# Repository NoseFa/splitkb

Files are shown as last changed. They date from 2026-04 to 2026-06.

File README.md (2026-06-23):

# Nordic split

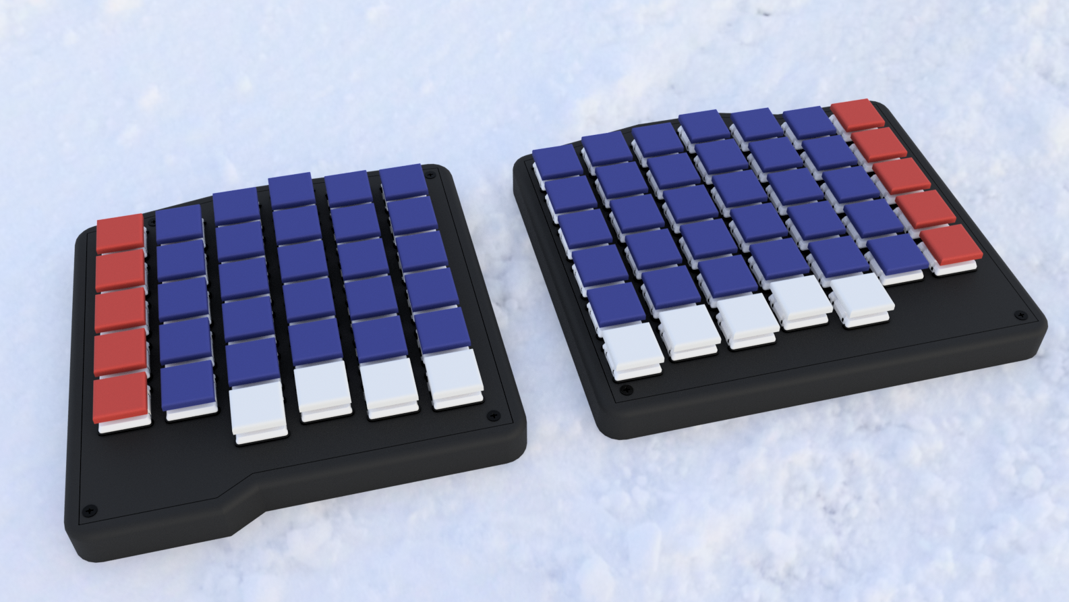
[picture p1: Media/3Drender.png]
3D render


A split low-profile wireless keyboard with a nordic ISO layout. I used the [Caldera Keyboard by Christian Selig](https://github.com/christianselig/caldera-keyboard) as inspiration and it clearly shows in the design. Still the keyboard uses a nice!nano like microcontroller based on the same NRF52840, ZMK as the firmware and a custom pcb with Choc V1 hotswap sockets. The keyboard also has an ortholinear layout which can be more ergonomic for some users.

The project was made and designed as a part of Hack Club's [Fallout](https://fallout.hackclub.com/) event where people make hardware projects and get a chance to go to Shenzhen, China. This was also one of my first electronics projects.

## Highlights

* Hotswapping
* Open-source
* ZMK firmware (ZMK studio support)
* Wireless
* Nordic layout
* total of 74 keys

## Why it exists?

The project was made because I wanted a split keyboard but needed a nordic layout for my day to day stuff (I need the letters Ä, Ö, Å). So the nordic split was born. I took inspiration from the Caldera keyboard by Christian Selig. It's low profile so it can be transported easily around and it's also wireless so no need for annoying dual or split cables for connecting to a computer or laptop.

This is the first keyboard I have designed so the keymap and layout were made with some educated guess work. They might be updated later down the line. I will update this repo with the most recent keymap I use. Even though it was designed as nordic layout first. The keyboard could also be used by people with non-nordic layouts and you could use the extra row of keys on the right side as shortcut or macro keys. Of course also the pcb could be edited and these keys removed if you don't want them. This keyboard has ZMK studio support so you can change the keymap in the [ZMK.studio](https://zmk.studio) web app.

## BOM summary

* Pro Micro NRF52840 [Aliexpress](https://www.aliexpress.com/item/1005007205026373.html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)
* Kailh choc v1 low-profile switches [Aliexpress](https://www.aliexpress.com/item/1005008644185126.html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)
* 304050 Lithium-Polymer battery [42Keebs.eu](https://42keebs.eu/shop/parts/lithium-polymer-battery/?attribute_size=304050%20(600%20mAh))
* Kailh Low Profile Choc hotswap sockets [Aliexpress](https://www.aliexpress.com/item/1005011893351142.html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)
* PCB [JLCPCB](https://cart.jlcpcb.com/quote?spm=jlcpcb.Public.2006)
* M2x8mm screws [Aliexpress](https://www.aliexpress.com/item/1005006995421098.html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)
* M2 3mm OD heated inserts [Aliexpress](https://www.aliexpress.com/item/1005006071488810.html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)
* SOD-123 Diodes [Aliexpress](https://www.aliexpress.com/item/1005007536719404.html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)
* Kailh choc V1 A keycaps [Aliexpress](https://www.aliexpress.com/item/1005009262759706.html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)
* Anti-slip pads [Aliexpress](https://www.aliexpress.com/item/1005007438396940.html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)

Total price for the whole build excluding 3d prints is 159.26€.

You can find the full [BOM here](BOM.csv). It includes pricing, amount of parts, extra info etc.

## Build Guide Summary

1. Order PCB and other parts.
2. Order or print the case.
3. Solder parts to the PCBs (Diodes, hotswap-sockets, microcontroller)
4. Install the heated threaded inserts to the spots in the case (4 per side)
5. Install the PCB to the case.
6. Install top plate.
7. Install the choc switches to the sockets and keycaps.
8. Flash software (Check software section)
9. Enjoy!

More detailed build guide is available in the [build guide.md file](buildGuide.md).

## Software

See [Software.md](./Software/software.md) for more info about software and software installation instructions. The software source code files are in a different repo ([NoseFa/nordic-split-zmk](https://github.com/NoseFa/nordic-split-zmk))

## PCB

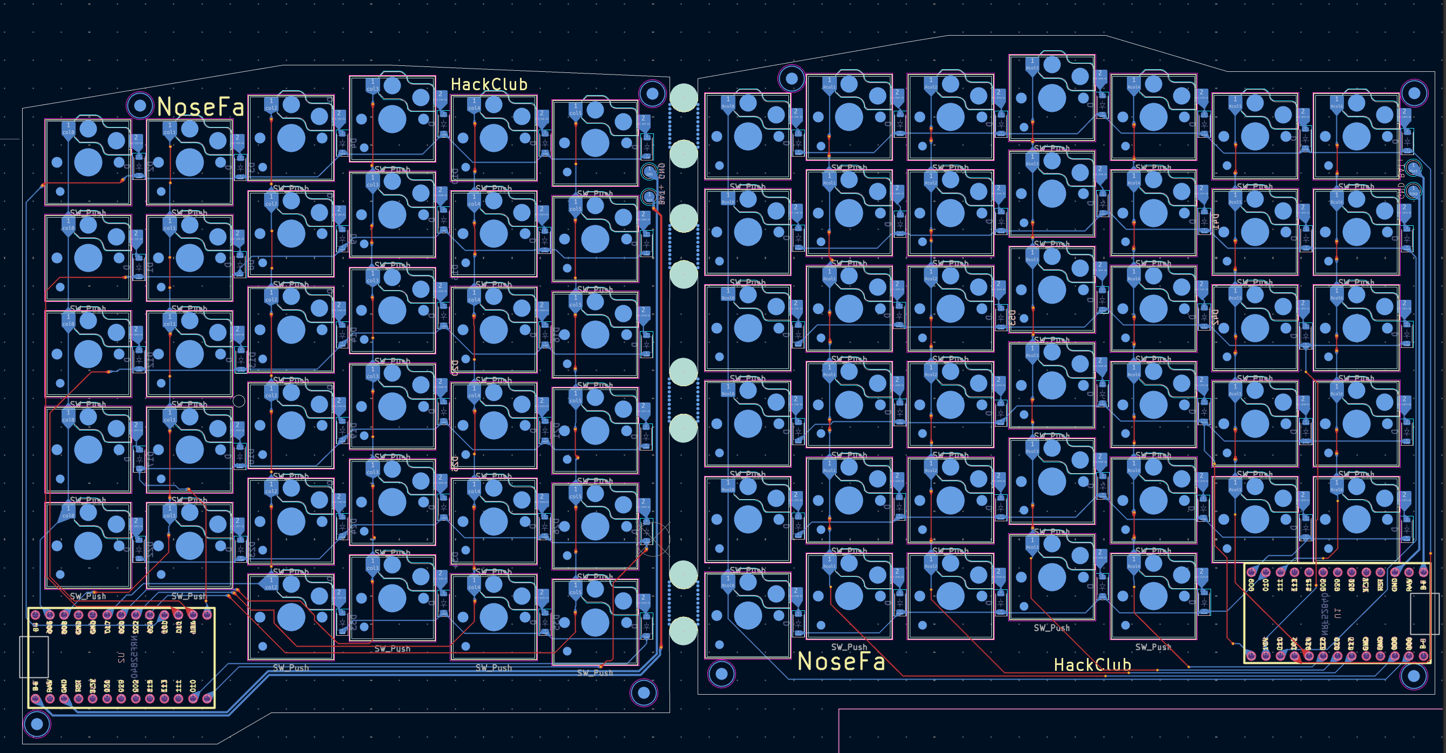
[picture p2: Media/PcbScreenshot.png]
PCB


Here is a picture of the left side PCB. You can see the switches, traces and a spot for the microcontrollers. The PCBs are seperated by mouse bites in the middle. Unlike some other split keyboards the Nordic Splits halves aren't mirrored but instead the right side has an extra row of keys primarly needed to support the Nordic layout.

The pcb was designed in KiCad by me. You can view the files in the [Kicad folder](./KICAD/splitkb).

Here is also the schematic which is split into three different pages. One for each side and one main page that has the mousebites and links the pages together.

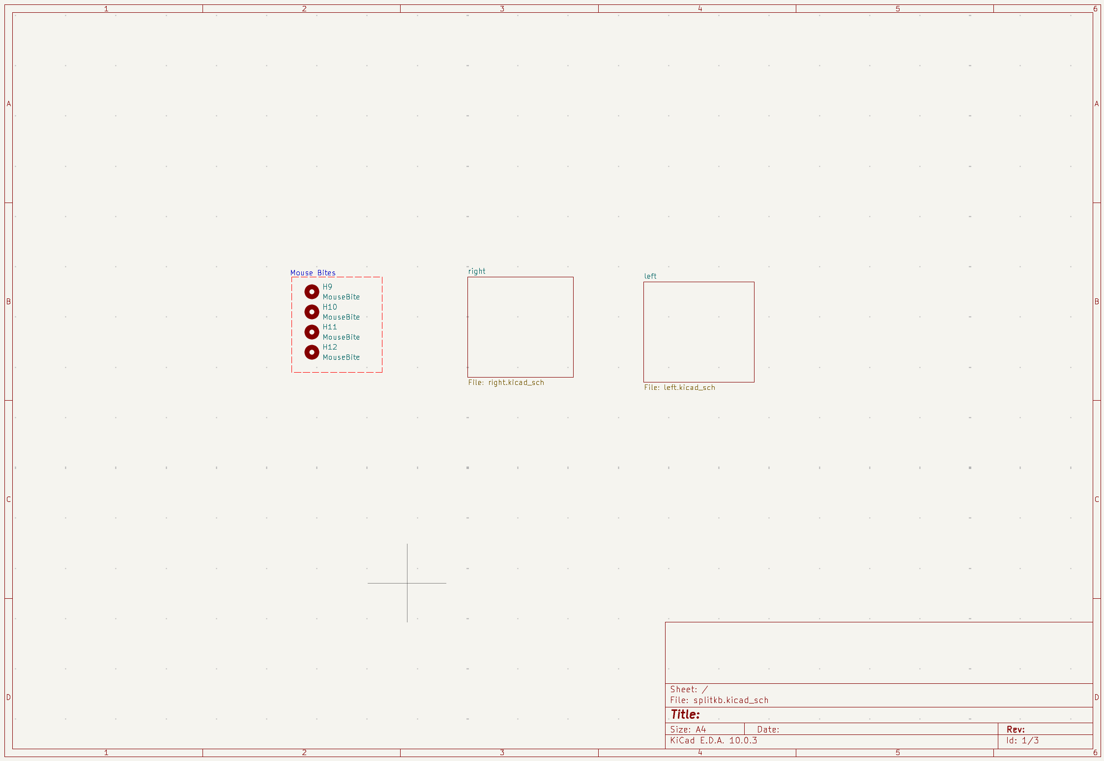
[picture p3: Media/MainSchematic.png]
Main Schematic


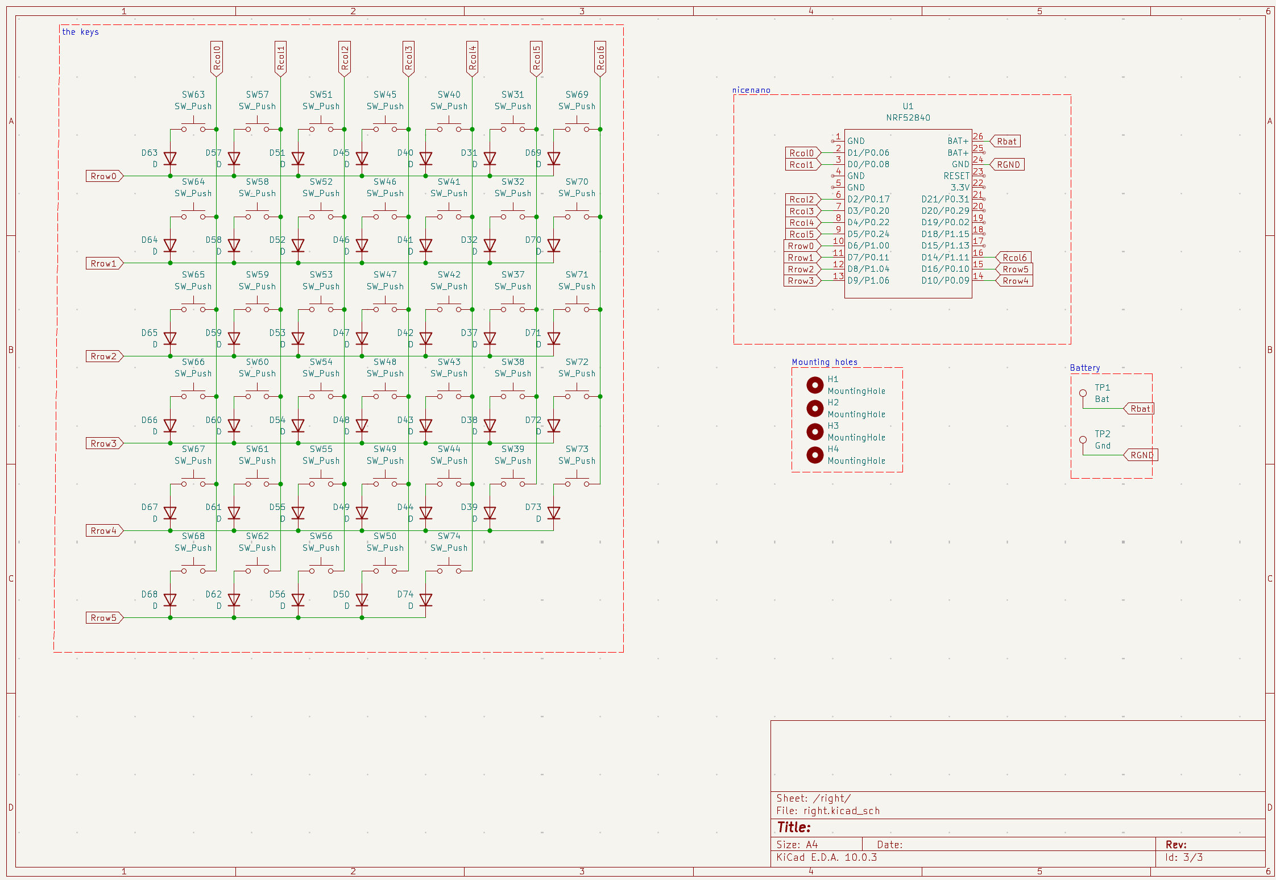
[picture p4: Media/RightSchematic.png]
Right side Schematic


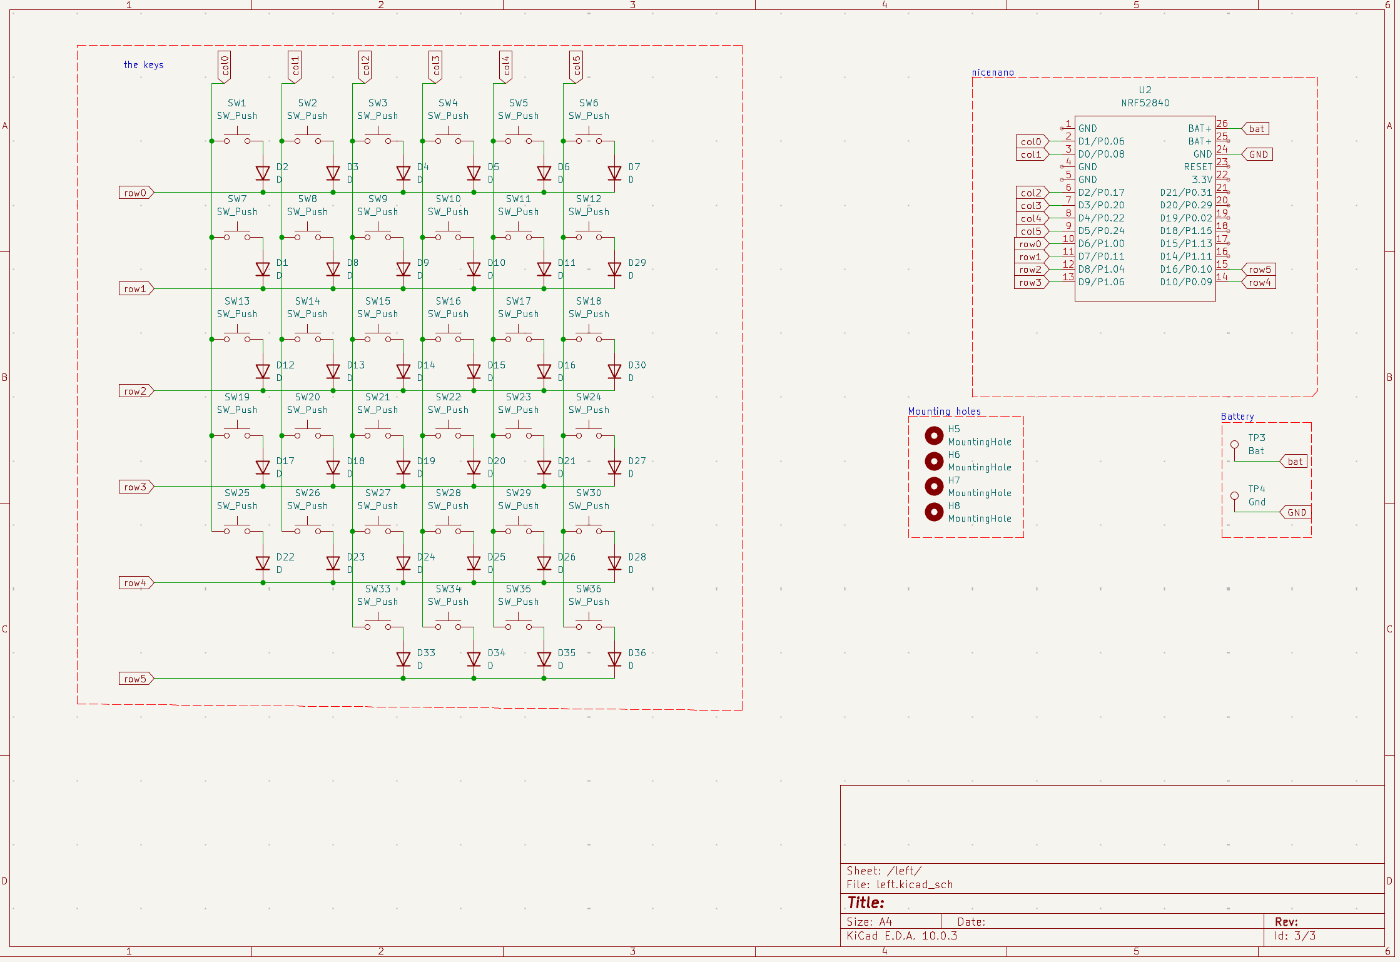
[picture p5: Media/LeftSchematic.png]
Left side Schematic


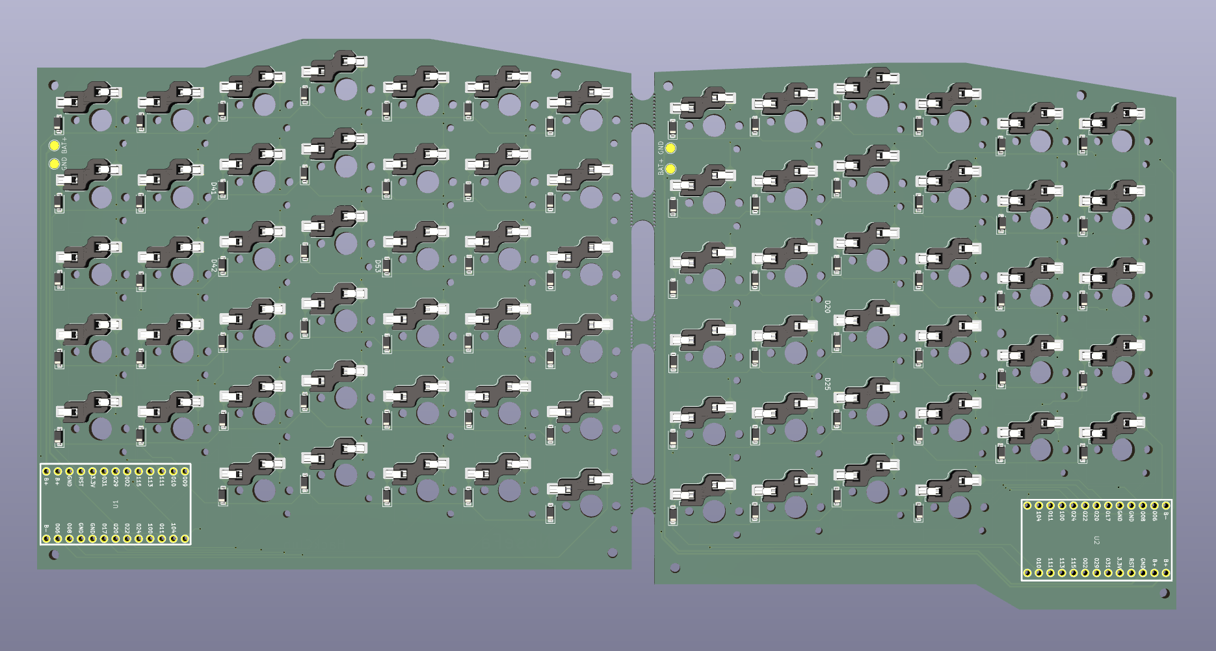
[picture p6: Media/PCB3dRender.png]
3D render of the pcb


For ordering the PCB I used JLCPCB. You can find the gerber files as a zip in the [Production files folder](./KICAD/ProductionFiles/NordicSplitGerber.zip)

## 3D files

3d Files are seperated into 2 folders. Full project which has the .fz3 and .step versions of the whole 3D project. The PCB was exported when I finished the the edge cuts so some holes next to the micro controller might be different. I didn't include the microcontroller or the SMD diodes in the 3d project but I did check that they fit.

The 3d files for the switches in the Fusion project are from [printables](https://www.printables.com/model/716753-kaliah-choc-v1-v2-dummy/files). They are made by [cobypear](https://www.printables.com/@cobypear_1543945). They are originally from the same library as I used in kicad which is the [kiswitch library](https://github.com/kiswitch/kiswitch/tree/main/library/3dmodels/3d-library.3dshapes). You can find the original files from the link.

## Zine Page

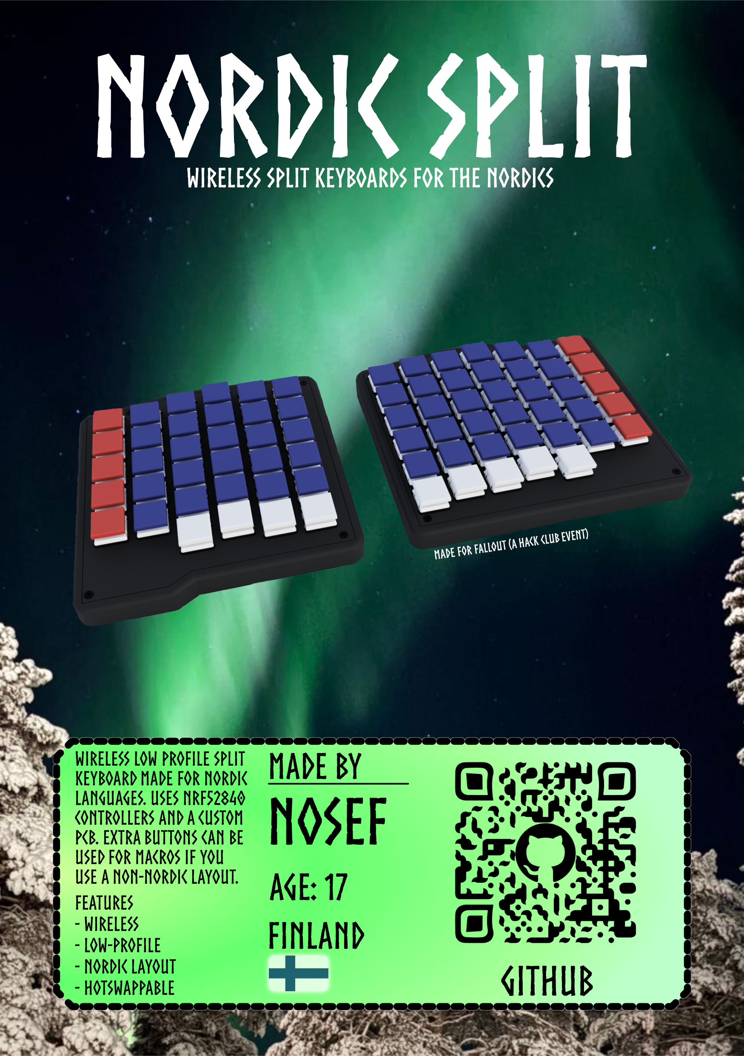
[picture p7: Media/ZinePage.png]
Zine Page


Zine page is also available as a [PDF](./ZinePage/ZinePage.pdf).
Background picture was taken by my dad when we went up north.

## Demo

A video of the keyboard in use.

SOON (When I get the parts).

## Acknowledgements

* Thanks to [Hack Club](https://hackclub.com/) [Fallout](https://fallout.hackclub.com/). If you want to view the project I made for Fallout including journals you can view it on [the event page](https://fallout.hackclub.com/projects/156).

* [Caldera Keyboard by Christian Selig](https://github.com/christianselig/caldera-keyboard) was used as inspiration and [his video](https://www.youtube.com/watch?v=7UXsD7nSfDY) was a great watch. My design is clearly inspired by him.

## Tools used

### Design

* [KiCad](https://www.kicad.org/) (PCB design)
* [Fusion](https://www.autodesk.com/products/fusion-360/personal) (Case design)
* [Excalidraw](https://app.excalidraw.com/) (Notetaking)
* [ZMK CLI](https://zmk.dev/docs/zmk-cli) (Firmware creation)

### Assembly

* Soldering iron
* Screwdriver for the M2 screws
* Computer to flash the software.
* USB-C cable

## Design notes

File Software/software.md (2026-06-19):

# Software

> [!WARNING]
> The software source code files are in a different repo ([NoseFa/nordic-split-zmk](https://github.com/NoseFa/nordic-split-zmk))

The keyboard is running ZMK which is the standard software used for wireless diy custom keyboards. Here is the [official docs for ZMK](https://zmk.dev/docs/features/split-keyboards). You might want to read this if you want to know more. I will still provide some instructions and info here as well as my own config files in the [the software repo](https://github.com/NoseFa/nordic-split-zmk) but if you need something else you should check the ZMK page.

The main points you might want to know are that one of the sides will be the host and it will drain more battery then the other side. This is because the "host" side will be communicating between the computer and the other side and the non host side will be just communicating with the host side. With the size of the batteries I used this wont be an issue but this technically means that you could use a bit of a smaller battery on one side and have the same battery life as the host side. The software is configured using a different config files that have the keymap and gpio layout etc. Then ZMK has a github action that can create the .uf2 file. The ready to install firmware is available in [the firmware folder](./firmware/). I have added ZMK studio support so some configuration of the keymap can be done through [the ZMK studio web tool](https://zmk.studio/). There is also a [native app](https://zmk.studio/download). This can be useful if you want to change the keymap but don't want to make a whole new .uf2 software file.

If you want to view to more specific config files and builds you can view [the software repo](https://github.com/NoseFa/nordic-split-zmk). If you're just looking to install the firmware you can use the files in the [firmware folder](./firmware). Remember that there are different files for each side.

## Installation

For installing you can grab the .uf2 files from the software folder. You can also edit the config files if you want to modify them and make your own .uf2 files. You can enter the flashing mode of the ProMicro by shorting the Rst(Reset) and GND(Ground) pins for 0,5swhile connecting to your computer and the controller should show up as a Nice!Nano storgae media device. You can drop in the .uf2 file on it and it should install it. You have seperate firmware files for each side ([`nordic1_left-nice_nano_v2-zmk.uf2`](./firmware/nordic1_left-nice_nano_v2-zmk.uf2) and [`nordic1_right-nice_nano_v2-zmk.uf2`](./firmware/nordic1_right-nice_nano_v2-zmk.uf2)) check that you have the right one before you flash it. There are different layouts so this is important. After flashing them they should boot into the ZMK firmware and they should link together automatically through their paring process. See [the ZMK troubleshooting guide](https://zmk.dev/docs/troubleshooting/connection-issues). The keyboard should also become visible as a bluetooth device you can connect to. Keep in mind that only one device will show up and not both halves seperately.

## Keymaps

Here are the two layers included in the firmware files. There are also two empty layers that you can use using ZMK studio to configure anything you want without having to run the build action again. The icons in the previews are from Iconify. These keymaps are made with the nordic layout in mind and they are the first keymap I have created so they can be a little bit weird.

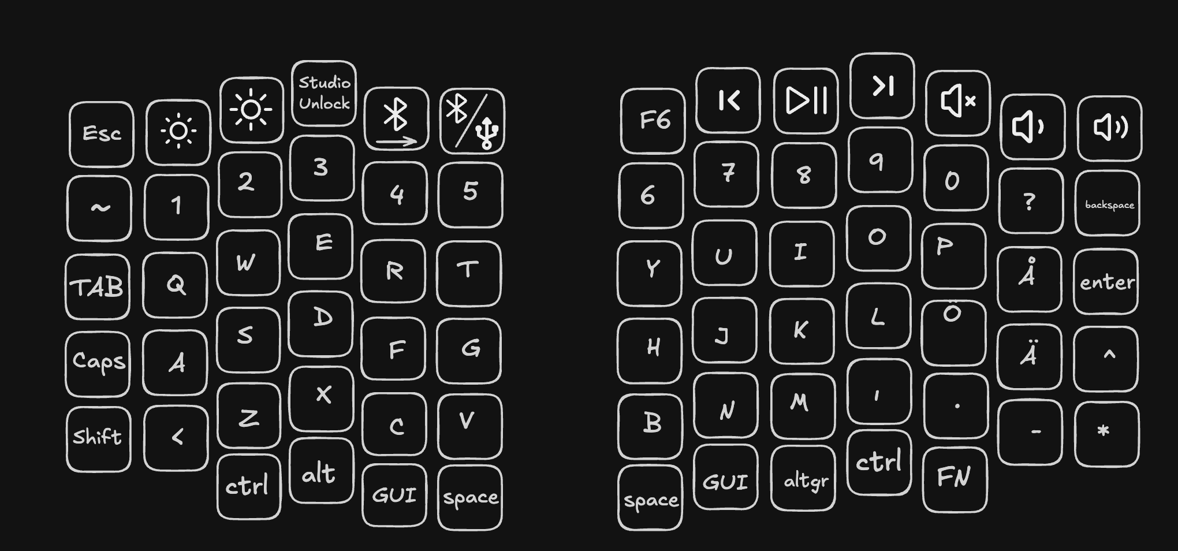
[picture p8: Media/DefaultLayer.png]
Default QWERTY layer


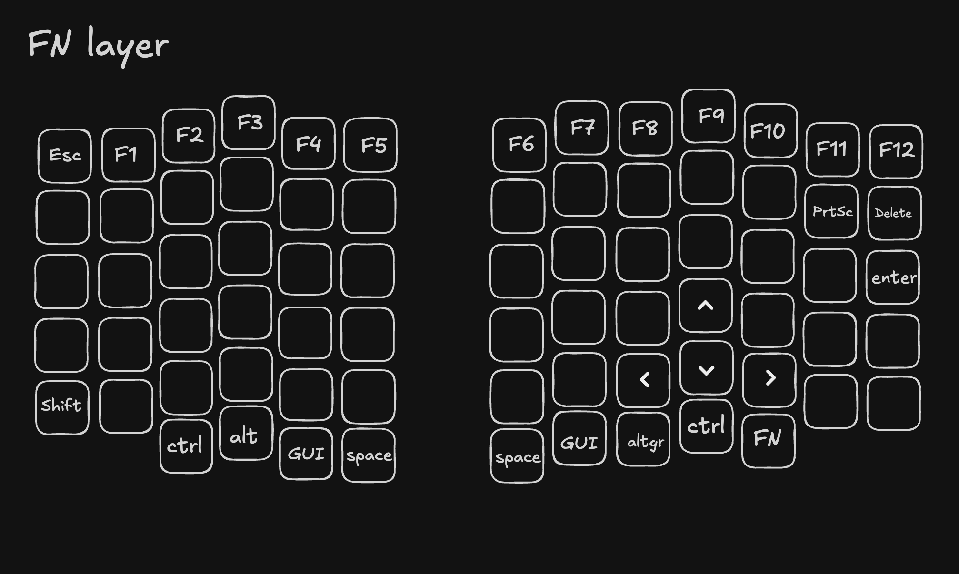
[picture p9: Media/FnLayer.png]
Function layer


## ZMK studio

ZMK studio is a tool provided by ZMK and for which I have added support in the firmware provided. You can use the easy to use GUI to change the keymap. The changes can be made even while the board is still connected to your computer and doesn't require reflashing. I have added 2 extra layers for which you can use for what ever you like. These have been left empty for now and should be configured by what you want. If you want to switch from the nordic keymap thats also made easier by ZMK studio and not having to flash the firmware again.

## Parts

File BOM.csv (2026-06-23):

Component | Price per order amount | parts needed | Shipping | Total price (For specific components) | Links | Extra info
Pro Micro NRF52840 | 4.13€ | 2 | Free | 8.23€ | https://www.aliexpress.com/item/1005007205026373.html?curPageLogUid=OxA2oroU7gov
Kailh Low Profile Choc Switches (brown) | 40.02€ for 80 switches | 74 | Free | 40.02€ | https://www.aliexpress.com/item/1005008644185126.html?curPageLogUid=ON5BcLwWvUu1
304050 Lithium-Polymer battery | 8.79€ for 1 pcs | 2 | 11.92€ | 29.50€ | https://42keebs.eu/shop/parts/lithium-polymer-battery/?attribute_size=304050%20(600%20mAh) | Needs to be ordered from within the EU to pass customs. If you live outside the EU you should look at local providers or on aliexpress
Kailh Low Profile Choc hotswap sockets | 8.58€ for 90 pieces | 74 | Free | 8.58€ | https://www.aliexpress.com/item/1005011893351142.html?curPageLogUid=nRsxJkAXhesI
PCB | 16.36€ for 5 pcs | 1 needed but is 5 minimum order amount. | 22.51€ + 9.92€ (Customs and taxes) | 48.79€ | https://cart.jlcpcb.com/quote?spm=jlcpcb.Public.2006 | Used europacket as the shipping option because they handle the taxes and it was the cheapest option.
M2x8mm screws | 0.86€ for 100 pcs | 4 | Free | 0.86€ | https://www.aliexpress.com/item/1005006995421098.html?curPageLogUid=HEtOGF0Rf2DI
M2 3mm OD L 3mm heated inserts | 1.23€ for 30 pcs | 4 | Free | 1.23€ | https://www.aliexpress.com/item/1005006071488810.html?curPageLogUid=m7Avo8Kp89dD
SOD-123 diodes | 1.43€ for 100pcs | 74 | Free | 1.43€ | https://www.aliexpress.com/item/1005007536719404.html?curPageLogUid=43hY8FWrAoHt
Kailh choc 1350 V1 A keycaps | 22.99€ for 90 pcs | 74 | Free | 25.73€ | https://www.aliexpress.com/item/1005009262759706.html?curPageLogUid=vcYL3e40gH5n
4pcs anti-slip black rubber feet | 0.87€ for 4pcs | 8 | Free | 1.74€ | https://www.aliexpress.com/item/1005007438396940.html?scm_id=1007.40050.354490.0&scm-url=1007.40050.354490.0 | The purchase limit is 4 per person but you can order them from here as well. https://www.aliexpress.com/item/1005012156552297.html?scm_id=1007.40050.354490.0&scm-url=1007.40050.354490.0 . They are the same.
Total price of all components: |  |  |  | 166.11€
NOTE!
Prices include VAT unless specified otherwise. (Everything except the JLCPCB order)
Some aliexpress pricing includes deals and first time buyer benefits etc. You might want to look for parts that have better deals at the time you are buying.
3D print pricing not included since I'm self printing. JLC3DP can print the parts for around 32€ depending on the material etc

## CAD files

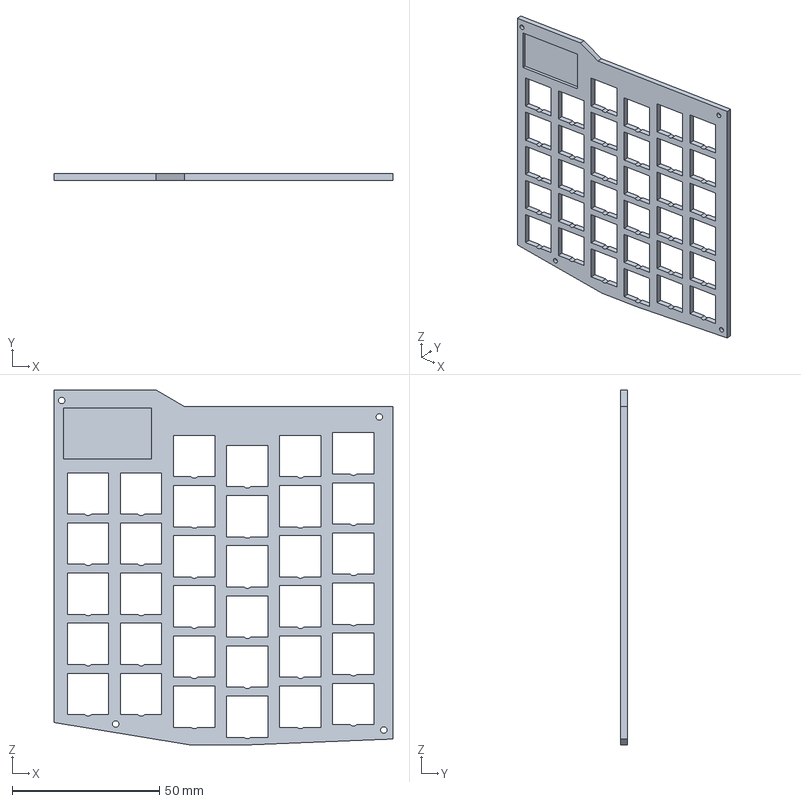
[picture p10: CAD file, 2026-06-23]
3dFiles/3dPrint/LeftSide/LeftSideTopPlate.step
114.8 x 2.50 x 120.4 mm

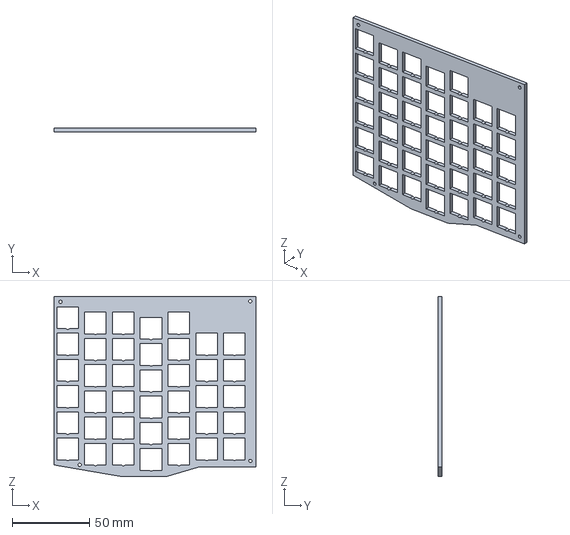
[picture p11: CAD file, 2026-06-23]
3dFiles/3dPrint/RightSide/RightSideTopPlate.step
130.8 x 2.50 x 116.8 mm

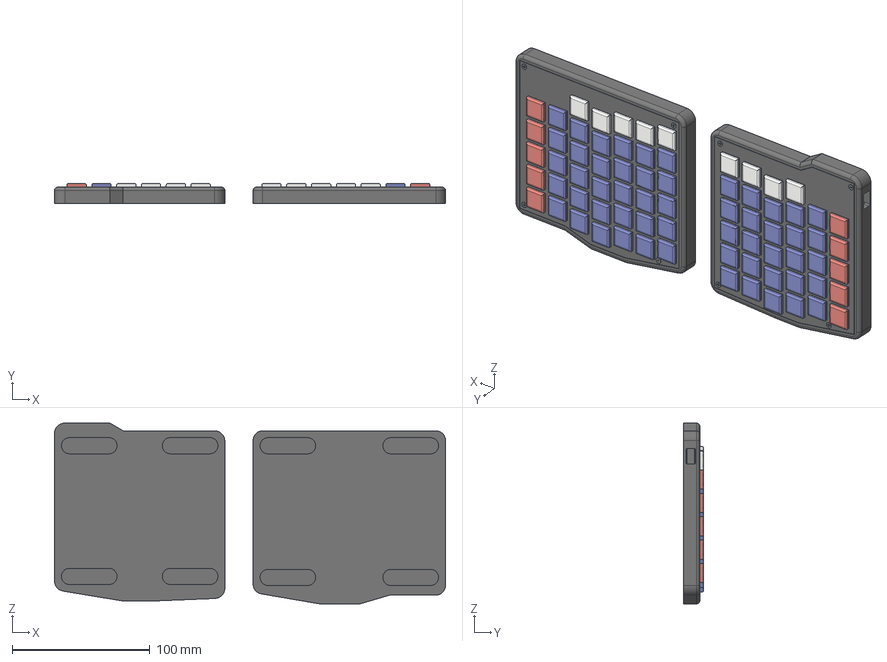
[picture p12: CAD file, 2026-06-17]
3dFiles/FullProject/SplitKbBothSides.step
284.1 x 14.4 x 131.4 mm
RightSideSplitKb
LeftSideSplitKb
PN-EN ISO 7046-1 - M2 x 8 - H Steel 4.6 Black x 8

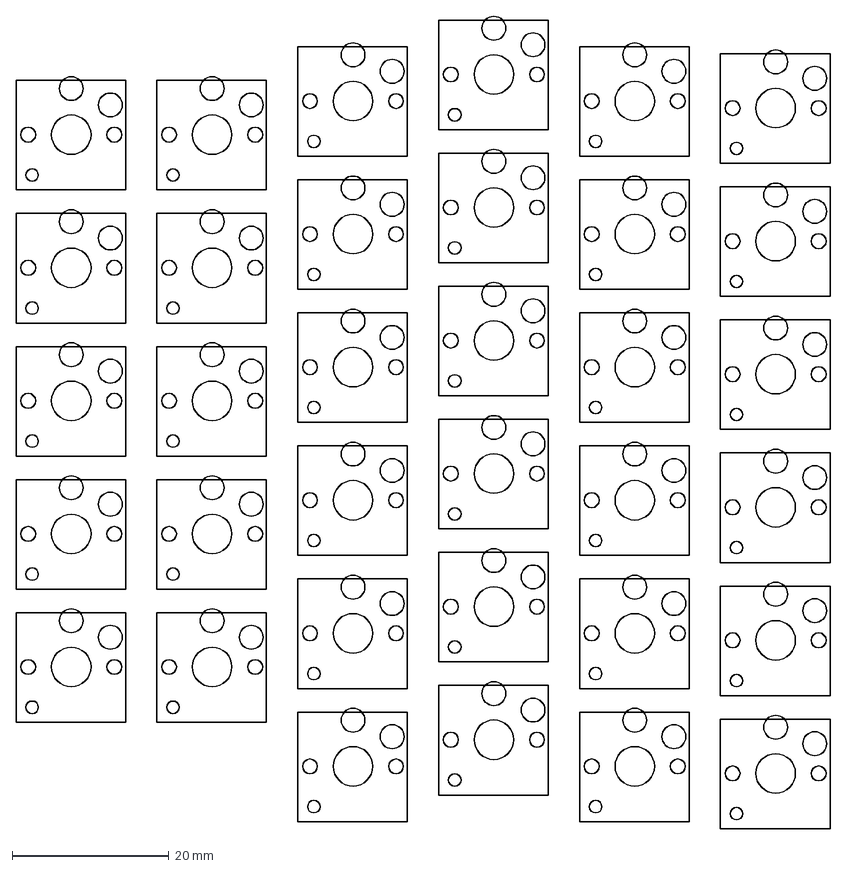
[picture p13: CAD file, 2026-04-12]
KICAD/splitkb/SketchLeft.dxf
104.0 x 103.8 mm

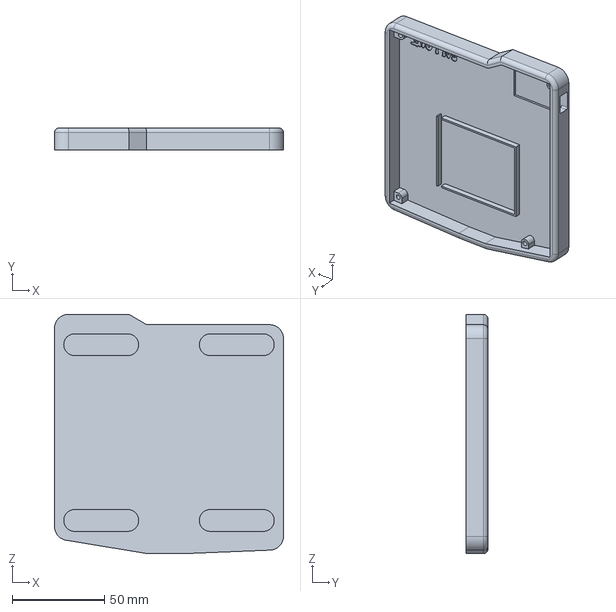
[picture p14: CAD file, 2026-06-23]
3dFiles/3dPrint/LeftSide/LeftSideOuterShell.step
123.8 x 11.9 x 129.4 mm

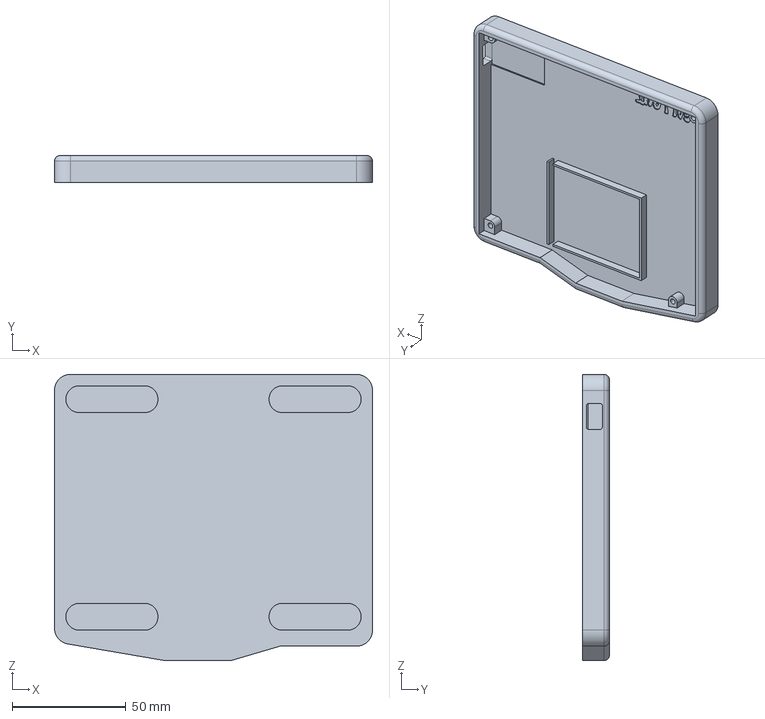
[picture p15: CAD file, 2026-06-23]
3dFiles/3dPrint/RightSide/RightSideOuterShell.step
139.8 x 11.9 x 125.8 mm

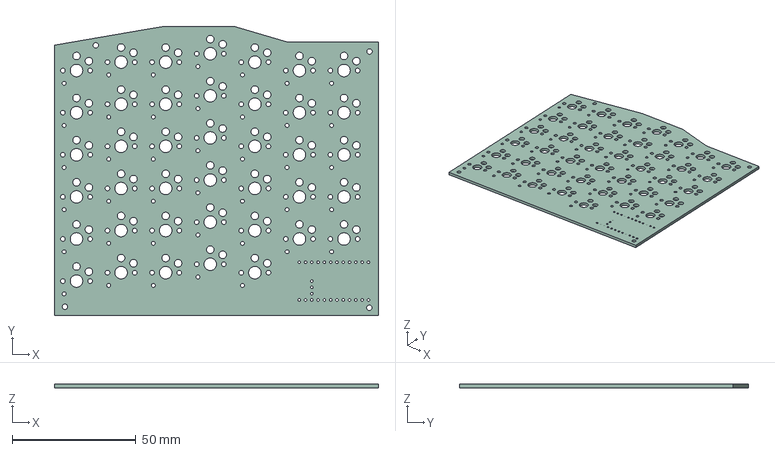
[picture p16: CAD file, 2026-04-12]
KICAD/splitkb/splitkb.step
130.8 x 116.8 x 1.51 mm

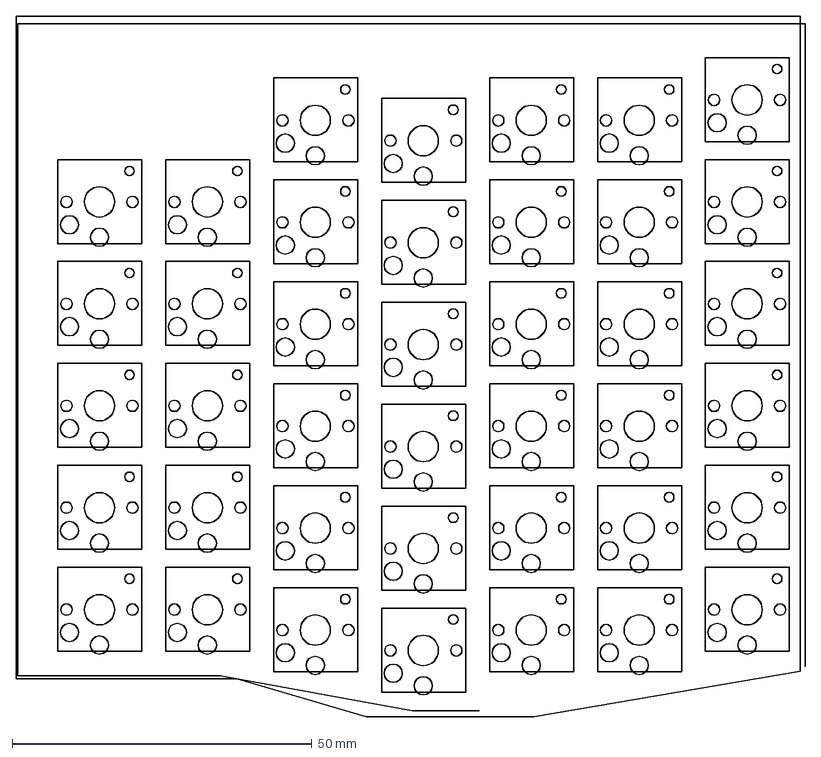
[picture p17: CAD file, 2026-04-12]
KICAD/splitkb/SketchRight.dxf
131.6 x 116.8 mm

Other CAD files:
3dFiles/3dPrint/LeftSide/LeftSideOuterShell.3mf
3dFiles/3dPrint/LeftSide/LeftSideTopPlate.3mf
3dFiles/3dPrint/RightSide/RightSideOuterShell.3mf
3dFiles/3dPrint/RightSide/RightSideTopPlate.3mf
3dFiles/FullProject/SplitKbBothSides.f3z

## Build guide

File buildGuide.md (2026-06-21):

# Build guide

This will cover building the physical keyboard. Part choices and ordering will be covered first.

## Ordering parts

First you need to order the PCBs from a PCB manufacturer. (Technically nothing prevents you from hand wiring this keyboard but it would require some redesigning of the case and is outside the scope of my project). I ordered just the PCB instead of a PCBA. They are pretty small and you could order it as a PCBA with the diodes preinstalled. I think I can manage to solder them and I will save some money as well. You can order the PCB or PCBA from a manufacturer like [JLCPCB](https://jlcpcb.com/). I order the PCB from them. They have a minimum order size of 5. So I order 5 bare PCBs from them and moved onto the next parts. For the board outline if it isn't automatically picked it's X = 251 mm and Y = 126 mm. When ordering you can try ordering the PCB as "one design". This might get flagged though since the two halves are different and might be considered two different designs. If you want to be 100% safe you should probably put 2 different designs. (At the time of writing I haven't ordered the PCB yet so I can't tell if they will accept this as one design.) Otherwise I left most things in the default option (Board thickness 1.6mm, 2 layers).

When buying the microcontroller you should buy a NRF52840 based dev board just check that it has the same pin layout etc. This is the one I bought [ProMicro NRF52840](https://www.aliexpress.com/item/1005007205026373.html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) from aliexpress. It is pretty much a copy of the Nice!Nano. The PCB and software have been made with this board in mind.

For the case you can either 3D print it yourself or you can use a manufacturer like [JLC3DP](https://jlc3dp.com/) to print the case. If you use [JLC3DP](https://jlc3dp.com/) and order the PCBs from [JLCPCB](https://jlcpcb.com/) you can save on total shipping costs. Using a printing service isn't listed in the BOM because I have a 3D printer that I can use for this. Remember to order both sides. So in total you should have different 4 parts to print (both sides have a case and top plate). You can find the files in the [3D files folder](./3dFiles/). The [Full project folder](./3dFiles/FullProject/) has the full 3D project inc. PCB, switches etc. It's available in .step and .f3z formats. There is also a [3d Print folder](./3dFiles/3dPrint/). It has ready to print files in .step format. All parts can be printed in place without supports.

For keycaps you can either 3d print them or follow the [BOM](BOM.csv) where you can find the keycaps I bought from aliexpress and the keycaps weren't that expensive especially compared to the amount of work I would need to sand and post process them and buying filament. If you don't care as much about the finish you can find keycaps on printables like the [KEA choc keycaps](https://github.com/klouderone/KEA-choc-keycaps) by [Klouderone](https://github.com/klouderone) and [Ross Douglas](https://github.com/rdougla3) ([License for their project](https://github.com/klouderone/KEA-choc-keycaps/blob/main/CC%20BY-NC%204.0.txt)). The anti-slip feet aren't mandatory but the case does have ready made spots for them and they aren't too expensive. So there is some money to save if you print the keycaps etc. The PCB was made so that the keys are upside down so just check that the keycaps you use are reversable.

For the other components like switches etc. you can look at [Bill of Materials](./BOM.csv). For the switches you can pick if you want clicky or linear etc. but the PCB is designed for choc v1 switches specifically.

## The case

Depending on the print quality you may want to wet sand the parts and add a few coats of paint. This isn't strictly necessary but it can improve the feel and finish of the part and can make them look better.

After printing the top plate and main body and maybe finishing the part. Then you can press in the heated inserts to the main shell of both sides. You should attach them to the case assembly (there are pre made holes for them). After this you can move onto preparing the PCB for assembly.

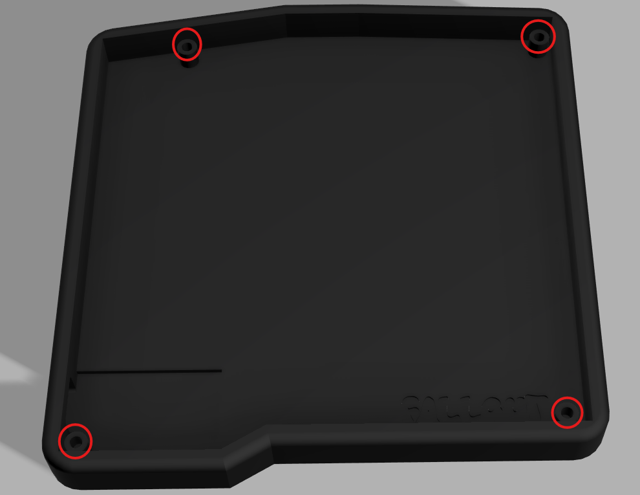
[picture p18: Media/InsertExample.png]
Heated insert spots


Here is a picture of the left side where I highlighted the heated insert spots. The right side is pretty much the same.

You should also install the non-slip pads to the bottom of the case if you bought them.

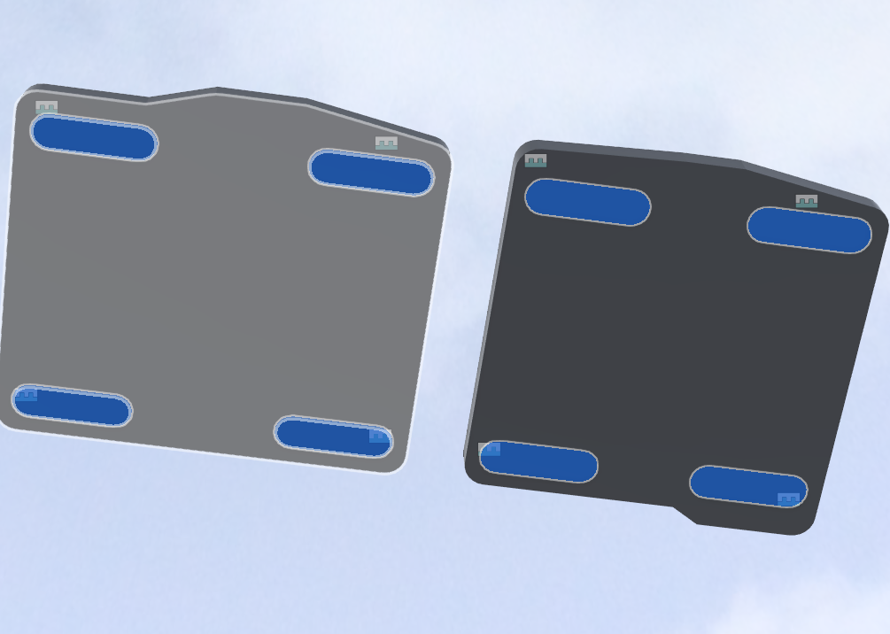
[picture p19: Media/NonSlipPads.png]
Non slip pad spots


Here is a picture with the spots for the pads highlighted.

## Working on the PCB

First you should seperate the sides from each other. They are seperated by mouse bites so you should be able to just almost like snap them from each other. Then you can attach the diodes and hotswap sockets (These might be preinstalled if you used an assembly service when ordeing the parts from the manufacturer). The diodes can be annoying to solder so you might want to use solder paste and an oven to make installation easier. Then you should install the dev board (ProMicro NRF52840 if you followed the BOM).  You should have pre-installed pins or pins installed by you on the board and you can solder it to the pcb using them. Now I would suggest connecting to a computer and flashing the software (See [software flashing](./Software/software.md) section if you need help). You can use metallic tweezers to bridge a connection and test each socket without installing switches (Just bridge the two points).

After you have tested each key and checked that it works you can move onto the next step. If it doesn't work check your soldering of the dev board and check the PCB. When ordering from companies like JLCPCB you usually have to get a min of 5 boards so you have extras just incase. You can try one of the other boards incase one of the PCBs had a manufacturing mistake etc.

If everything works you should move onto installing the battery to the PCB. You can solder the lead of battery to the pads on the PCB check that you attach the positive side to the BAT+ pad and the negative side to the GND pad. After this you can install the battery and PCB into the case and you should place the battery in first (Having long enough battery leads might be a help here). If you want to you can use some double sided tape to hold the battery in its holder. Then you can place the battery in the holder made for it in the center of the case. Next you can place the PCB on top of the stand offs and you can move on to installing the top plate and move onto installing the switches. Both sides can be assembled in the same way so you can follow this guide for both. Remember to connect the battery JST connector and the battery together.

## The switches

You should be able to just push in every switch. Keep in mind that the switches go on upside down. The hotswap sockets make this possible and there is no need to solder anything on the switches themselves. Check this render of one of the switches attached if you need help.

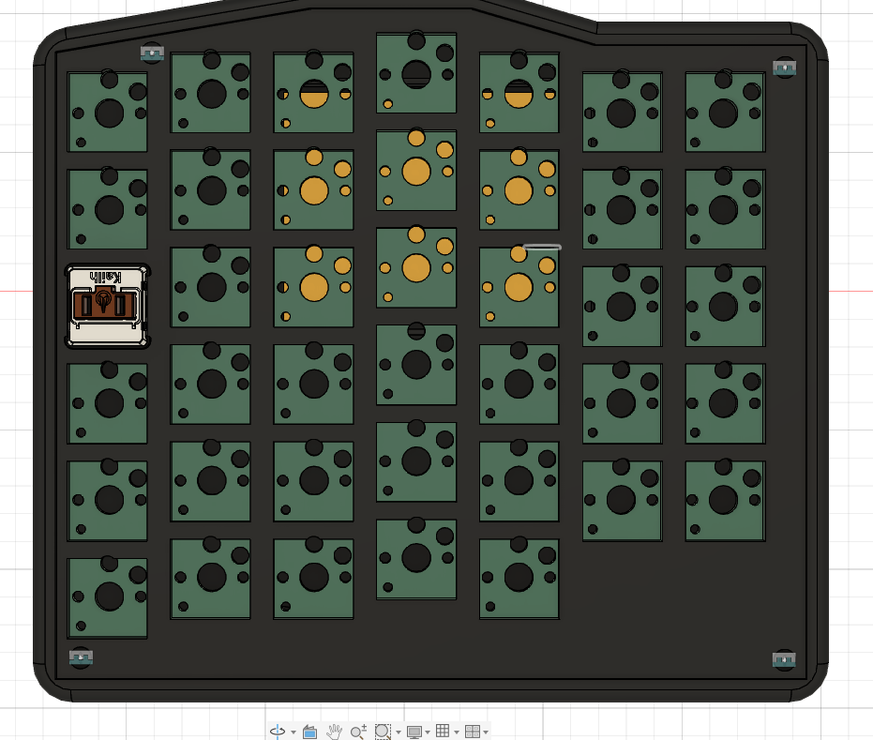
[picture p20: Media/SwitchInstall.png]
Switches installed


After the switches you should once again plug in both boards and check the firmware. When powered on the sides should sync together automatically. You should see only one keyboard in your bluetooth paring. Try to connect to it and test the keys. If everything works as intended you can install the keycaps and then your done. For the keycaps you can also just push them onto the switches.

## Software install

See [Software.md](./Software/software.md) for more info about software and software installation instructions. If you know what you're doing you can find the firmware files in the [Firmware folder](./Software/firmware/). If you want to see the config files they are in a different [software repo](https://github.com/NoseFa/nordic-split-zmk).

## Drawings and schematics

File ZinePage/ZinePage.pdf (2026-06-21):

# Nordic SPLIT

## Wireless split keyboards for the nordics

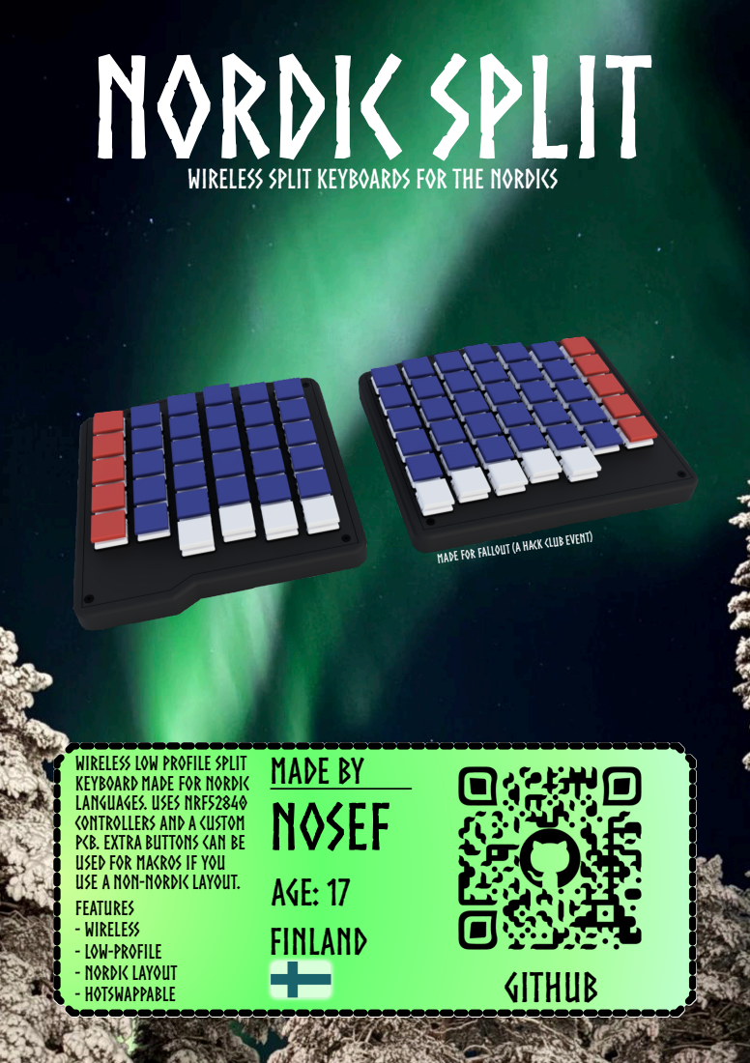
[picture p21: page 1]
NoseF; Github; Age: 17 Finland

Made for Fallout (a Hack club event)

Made by Wireless Low profile split
keyboard made for nordic
languages. Uses nRF52840
controllers and a custom
pcb. Extra buttons can be
used for macros if you
use a non-nordic layout.
Features
- Wireless
- low-profile
- Nordic layout
- HotSwappable

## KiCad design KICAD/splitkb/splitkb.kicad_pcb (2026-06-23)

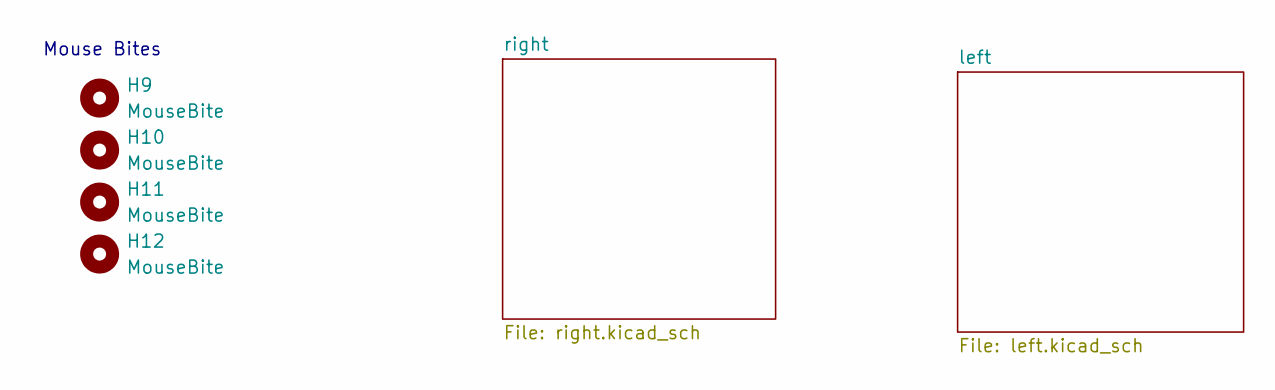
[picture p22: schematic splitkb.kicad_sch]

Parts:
H9, H10, H11, H12: MouseBite; mouse-bite-5mm-slot

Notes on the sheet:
Mouse Bites

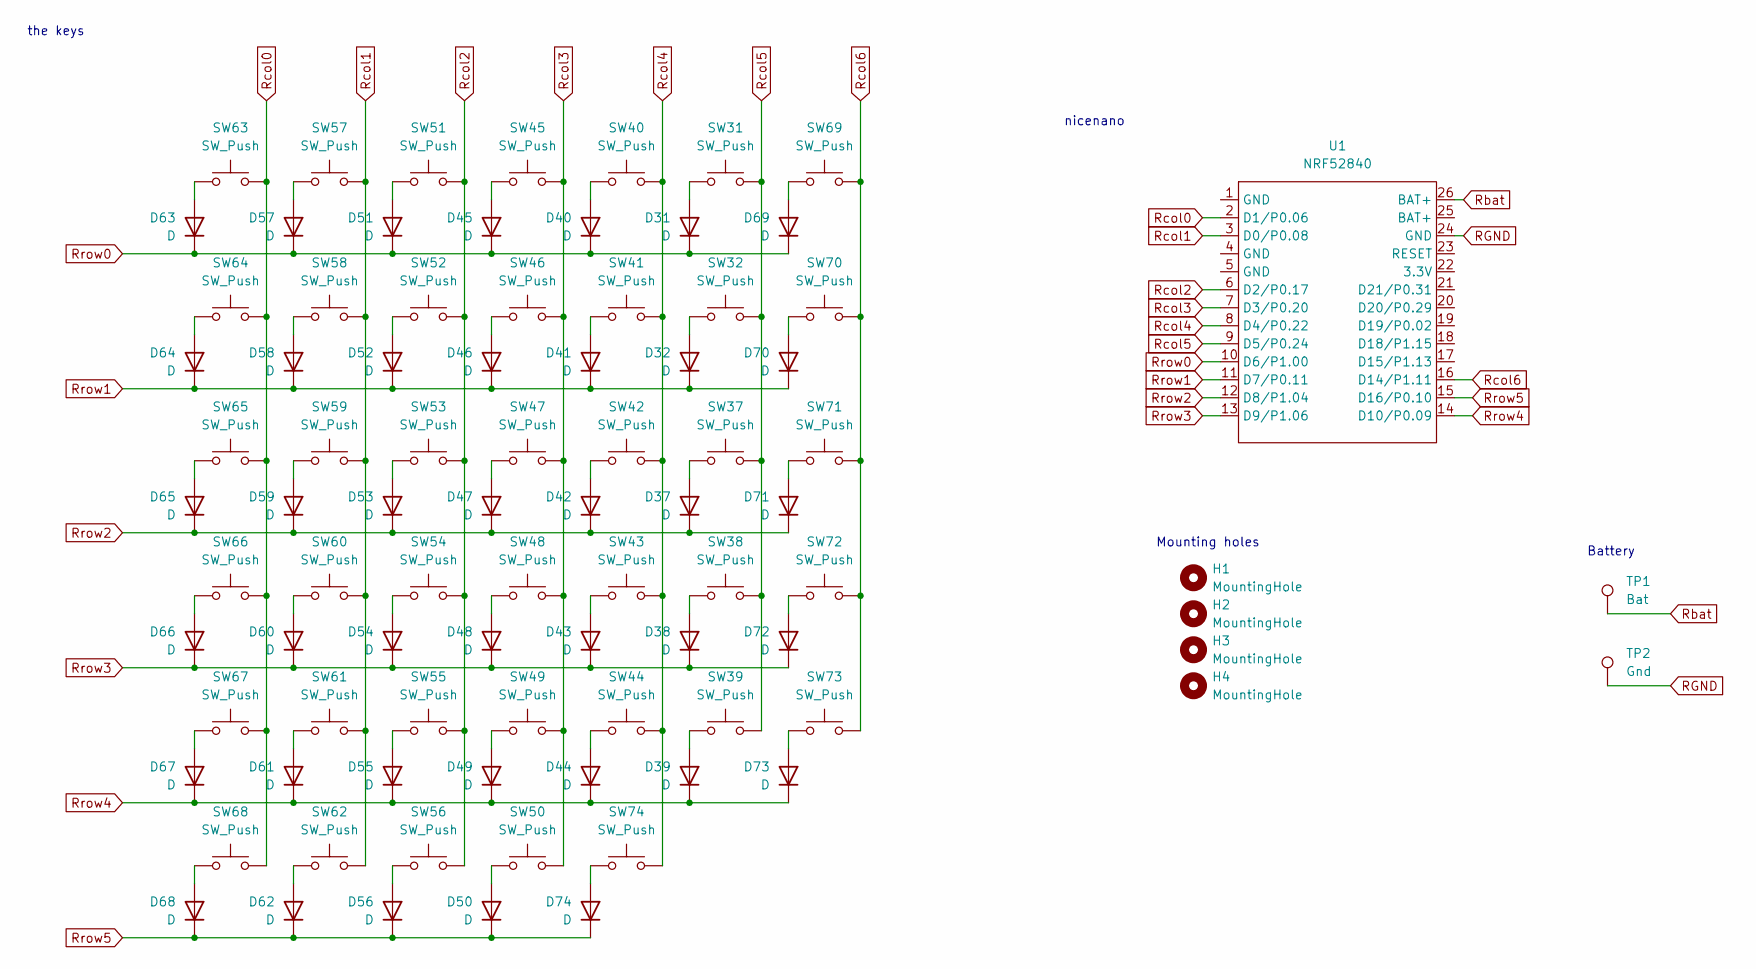
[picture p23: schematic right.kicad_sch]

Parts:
D31, D32, D37, D38, D39, D40, D41, D42, D43, D44, D45, D46, D47, D48, D49, D50, D51, D52, D53, D54, D55, D56, D57, D58, D59, D60, D61, D62, D63, D64, D65, D66, D67, D68, D69, D70, D71, D72, D73, D74: D; D_SOD-123
H1, H2, H3, H4: MountingHole; MountingHole_2.2mm_M2
SW31, SW32, SW37, SW38, SW39, SW40, SW41, SW42, SW43, SW44, SW45, SW46, SW47, SW48, SW49, SW50, SW51, SW52, SW53, SW54, SW55, SW56, SW57, SW58, SW59, SW60, SW61, SW62, SW63, SW64, SW65, SW66, SW67, SW68, SW69, SW70, SW71, SW72, SW73, SW74: SW_Push; SW_Hotswap_Kailh_Choc_V1V2
TP1: Bat; TestPoint_Pad_D2.0mm
TP2: Gnd; TestPoint_Pad_D2.0mm
U1: NRF52840

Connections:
unnamed: D31.2 (A), SW31.2
unnamed: D32.2 (A), SW32.2
unnamed: D37.2 (A), SW37.2
unnamed: D38.2 (A), SW38.2
unnamed: D39.2 (A), SW39.2
unnamed: D40.2 (A), SW40.2
unnamed: D41.2 (A), SW41.2
unnamed: D42.2 (A), SW42.2
unnamed: D43.2 (A), SW43.2
unnamed: D44.2 (A), SW44.2
unnamed: D45.2 (A), SW45.2
unnamed: D46.2 (A), SW46.2
unnamed: D47.2 (A), SW47.2
unnamed: D48.2 (A), SW48.2
unnamed: D49.2 (A), SW49.2
unnamed: D50.2 (A), SW50.2
unnamed: D51.2 (A), SW51.2
unnamed: D52.2 (A), SW52.2
unnamed: D53.2 (A), SW53.2
unnamed: D54.2 (A), SW54.2
unnamed: D55.2 (A), SW55.2
unnamed: D56.2 (A), SW56.2
unnamed: D57.2 (A), SW57.2
unnamed: D58.2 (A), SW58.2
unnamed: D59.2 (A), SW59.2
unnamed: D60.2 (A), SW60.2
unnamed: D61.2 (A), SW61.2
unnamed: D62.2 (A), SW62.2
unnamed: D63.2 (A), SW63.2
unnamed: D64.2 (A), SW64.2
unnamed: D65.2 (A), SW65.2
unnamed: D66.2 (A), SW66.2
unnamed: D67.2 (A), SW67.2
unnamed: D68.2 (A), SW68.2
unnamed: D69.2 (A), SW69.2
unnamed: D70.2 (A), SW70.2
unnamed: D71.2 (A), SW71.2
unnamed: D72.2 (A), SW72.2
unnamed: D73.2 (A), SW73.2
unnamed: D74.2 (A), SW74.2
RGND: TP2.1, U1.24 (GND)
Rcol0: SW63.1, SW64.1, SW65.1, SW66.1, SW67.1, SW68.1, U1.2 (D1/P0.06)
Rcol1: SW57.1, SW58.1, SW59.1, SW60.1, SW61.1, SW62.1, U1.3 (D0/P0.08)
Rcol2: SW51.1, SW52.1, SW53.1, SW54.1, SW55.1, SW56.1, U1.6 (D2/P0.17)
Rcol3: SW45.1, SW46.1, SW47.1, SW48.1, SW49.1, SW50.1, U1.7 (D3/P0.20)
Rcol4: SW40.1, SW41.1, SW42.1, SW43.1, SW44.1, SW74.1, U1.8 (D4/P0.22)
Rcol5: SW31.1, SW32.1, SW37.1, SW38.1, SW39.1, U1.9 (D5/P0.24)
Rcol6: SW69.1, SW70.1, SW71.1, SW72.1, SW73.1, U1.16 (D14/P1.11)
Rrow0: D31.1 (K), D40.1 (K), D45.1 (K), D51.1 (K), D57.1 (K), D63.1 (K), D69.1 (K), U1.10 (D6/P1.00)
Rrow1: D32.1 (K), D41.1 (K), D46.1 (K), D52.1 (K), D58.1 (K), D64.1 (K), D70.1 (K), U1.11 (D7/P0.11)
Rrow2: D37.1 (K), D42.1 (K), D47.1 (K), D53.1 (K), D59.1 (K), D65.1 (K), D71.1 (K), U1.12 (D8/P1.04)
Rrow3: D38.1 (K), D43.1 (K), D48.1 (K), D54.1 (K), D60.1 (K), D66.1 (K), D72.1 (K), U1.13 (D9/P1.06)
Rrow4: D39.1 (K), D44.1 (K), D49.1 (K), D55.1 (K), D61.1 (K), D67.1 (K), D73.1 (K), U1.14 (D10/P0.09)
Rrow5: D50.1 (K), D56.1 (K), D62.1 (K), D68.1 (K), D74.1 (K), U1.15 (D16/P0.10)

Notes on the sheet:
nicenano
the keys
Battery
Mounting holes

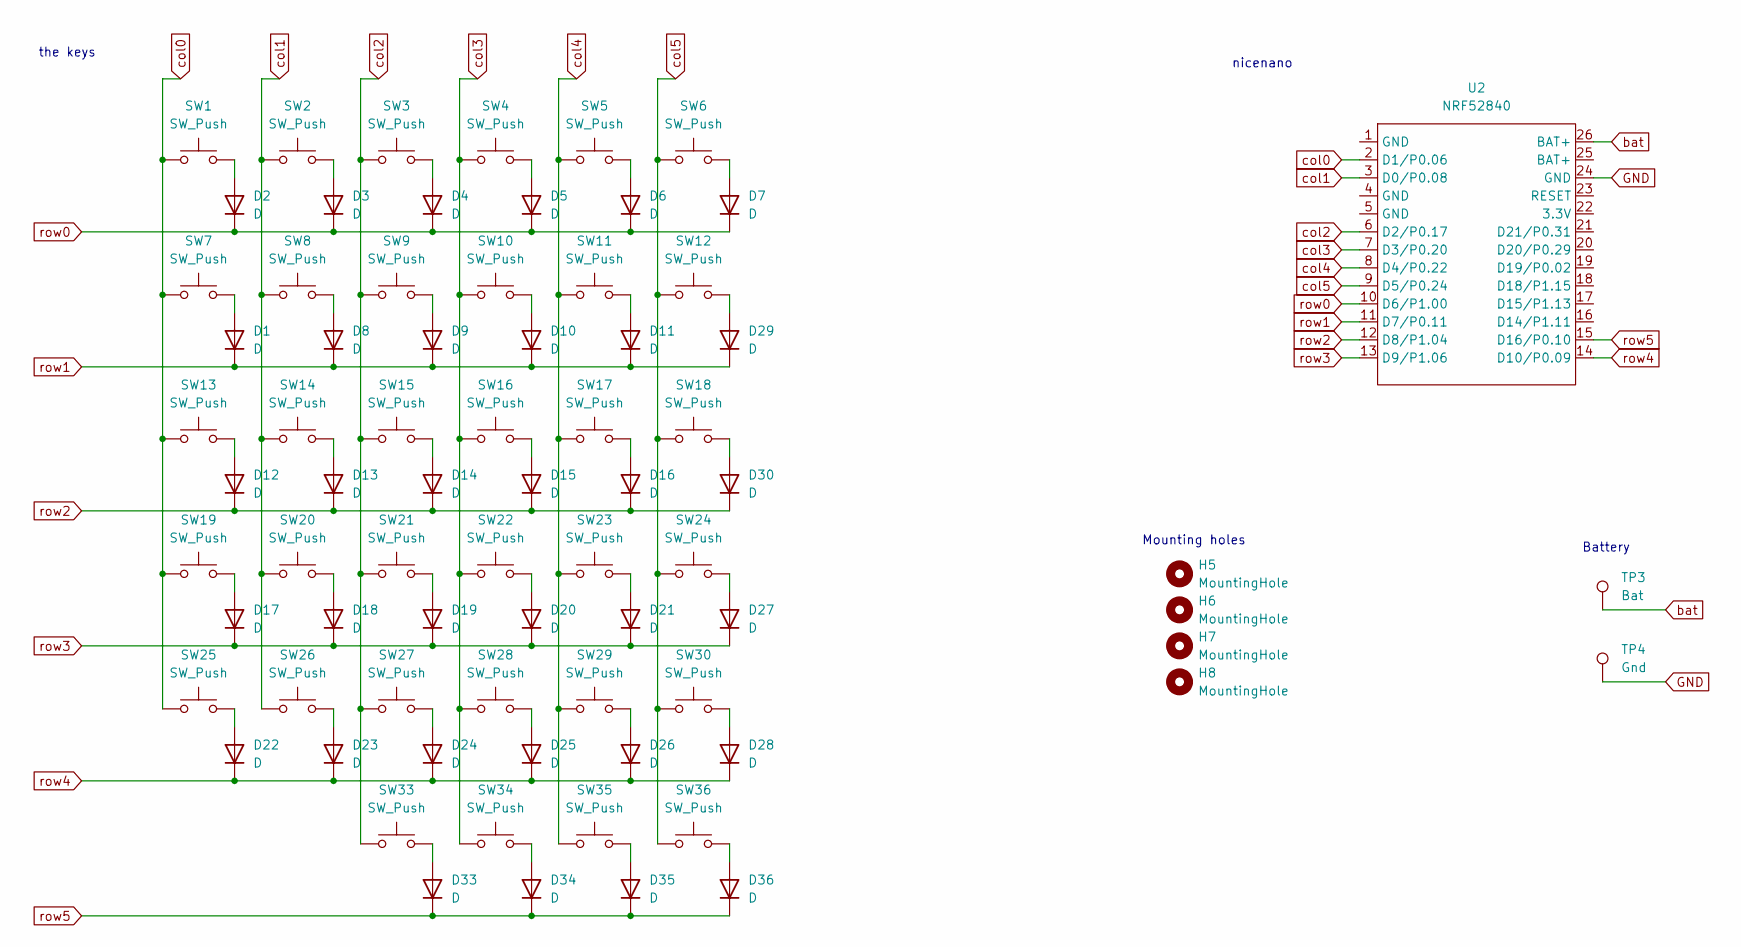
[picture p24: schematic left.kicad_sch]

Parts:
D1, D2, D3, D4, D5, D6, D7, D8, D9, D10, D11, D12, D13, D14, D15, D16, D17, D18, D19, D20, D21, D22, D23, D24, D25, D26, D27, D28, D29, D30, D33, D34, D35, D36: D; D_SOD-123
H5, H6, H7, H8: MountingHole; MountingHole_2.2mm_M2
SW1, SW2, SW3, SW4, SW5, SW6, SW7, SW8, SW9, SW10, SW11, SW12, SW13, SW14, SW15, SW16, SW17, SW18, SW19, SW20, SW21, SW22, SW23, SW24, SW25, SW26, SW27, SW28, SW29, SW30, SW33, SW34, SW35, SW36: SW_Push; SW_Hotswap_Kailh_Choc_V1V2
TP3: Bat; TestPoint_Pad_D2.0mm
TP4: Gnd; TestPoint_Pad_D2.0mm
U2: NRF52840

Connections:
GND: TP4.1, U2.24 (GND); also elsewhere on the board
unnamed: D1.2 (A), SW7.2
unnamed: D2.2 (A), SW1.2
unnamed: D3.2 (A), SW2.2
unnamed: D4.2 (A), SW3.2
unnamed: D5.2 (A), SW4.2
unnamed: D6.2 (A), SW5.2
unnamed: D7.2 (A), SW6.2
unnamed: D8.2 (A), SW8.2
unnamed: D9.2 (A), SW9.2
unnamed: D10.2 (A), SW10.2
unnamed: D11.2 (A), SW11.2
unnamed: D12.2 (A), SW13.2
unnamed: D13.2 (A), SW14.2
unnamed: D14.2 (A), SW15.2
unnamed: D15.2 (A), SW16.2
unnamed: D16.2 (A), SW17.2
unnamed: D17.2 (A), SW19.2
unnamed: D18.2 (A), SW20.2
unnamed: D19.2 (A), SW21.2
unnamed: D20.2 (A), SW22.2
unnamed: D21.2 (A), SW23.2
unnamed: D22.2 (A), SW25.2
unnamed: D23.2 (A), SW26.2
unnamed: D24.2 (A), SW27.2
unnamed: D25.2 (A), SW28.2
unnamed: D26.2 (A), SW29.2
unnamed: D27.2 (A), SW24.2
unnamed: D28.2 (A), SW30.2
unnamed: D29.2 (A), SW12.2
unnamed: D30.2 (A), SW18.2
unnamed: D33.2 (A), SW33.2
unnamed: D34.2 (A), SW34.2
unnamed: D35.2 (A), SW35.2
unnamed: D36.2 (A), SW36.2
col0: SW1.1, SW7.1, SW13.1, SW19.1, SW25.1, U2.2 (D1/P0.06)
col1: SW2.1, SW8.1, SW14.1, SW20.1, SW26.1, U2.3 (D0/P0.08)
col2: SW3.1, SW9.1, SW15.1, SW21.1, SW27.1, SW33.1, U2.6 (D2/P0.17)
col3: SW4.1, SW10.1, SW16.1, SW22.1, SW28.1, SW34.1, U2.7 (D3/P0.20)
col4: SW5.1, SW11.1, SW17.1, SW23.1, SW29.1, SW35.1, U2.8 (D4/P0.22)
col5: SW6.1, SW12.1, SW18.1, SW24.1, SW30.1, SW36.1, U2.9 (D5/P0.24)
row0: D2.1 (K), D3.1 (K), D4.1 (K), D5.1 (K), D6.1 (K), D7.1 (K), U2.10 (D6/P1.00)
row1: D1.1 (K), D8.1 (K), D9.1 (K), D10.1 (K), D11.1 (K), D29.1 (K), U2.11 (D7/P0.11)
row2: D12.1 (K), D13.1 (K), D14.1 (K), D15.1 (K), D16.1 (K), D30.1 (K), U2.12 (D8/P1.04)
row3: D17.1 (K), D18.1 (K), D19.1 (K), D20.1 (K), D21.1 (K), D27.1 (K), U2.13 (D9/P1.06)
row4: D22.1 (K), D23.1 (K), D24.1 (K), D25.1 (K), D26.1 (K), D28.1 (K), U2.14 (D10/P0.09)
row5: D33.1 (K), D34.1 (K), D35.1 (K), D36.1 (K), U2.15 (D16/P0.10)

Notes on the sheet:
the keys
Mounting holes
Battery
nicenano

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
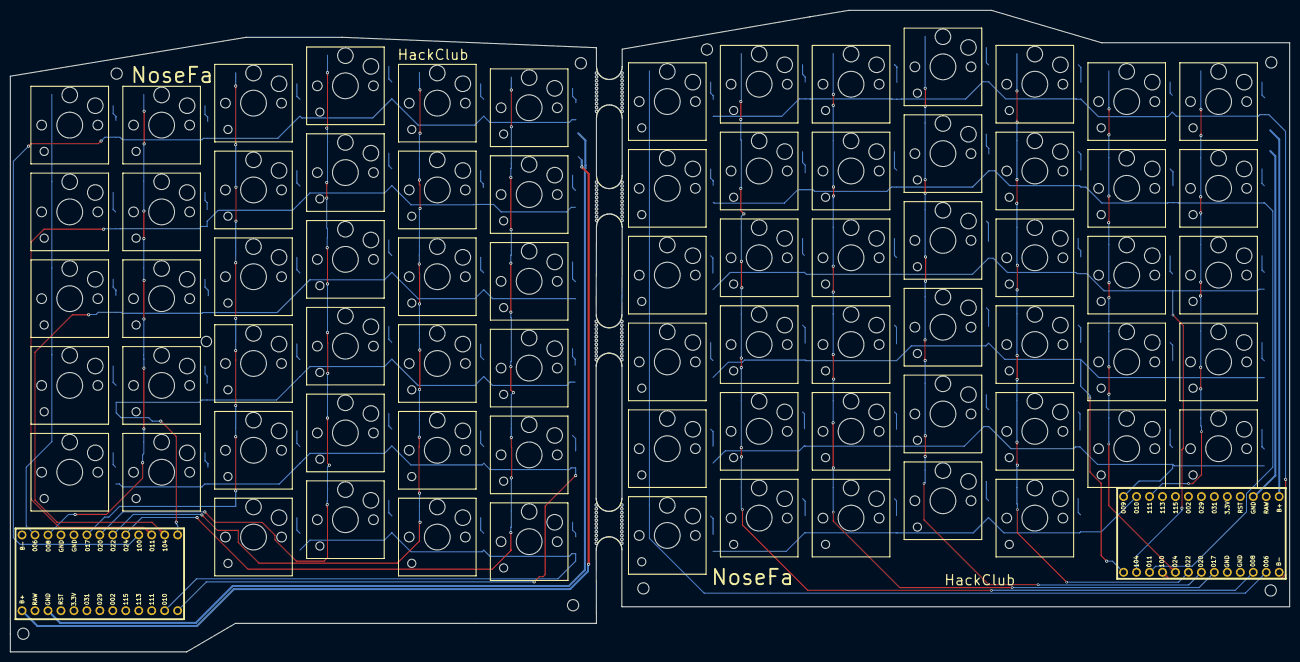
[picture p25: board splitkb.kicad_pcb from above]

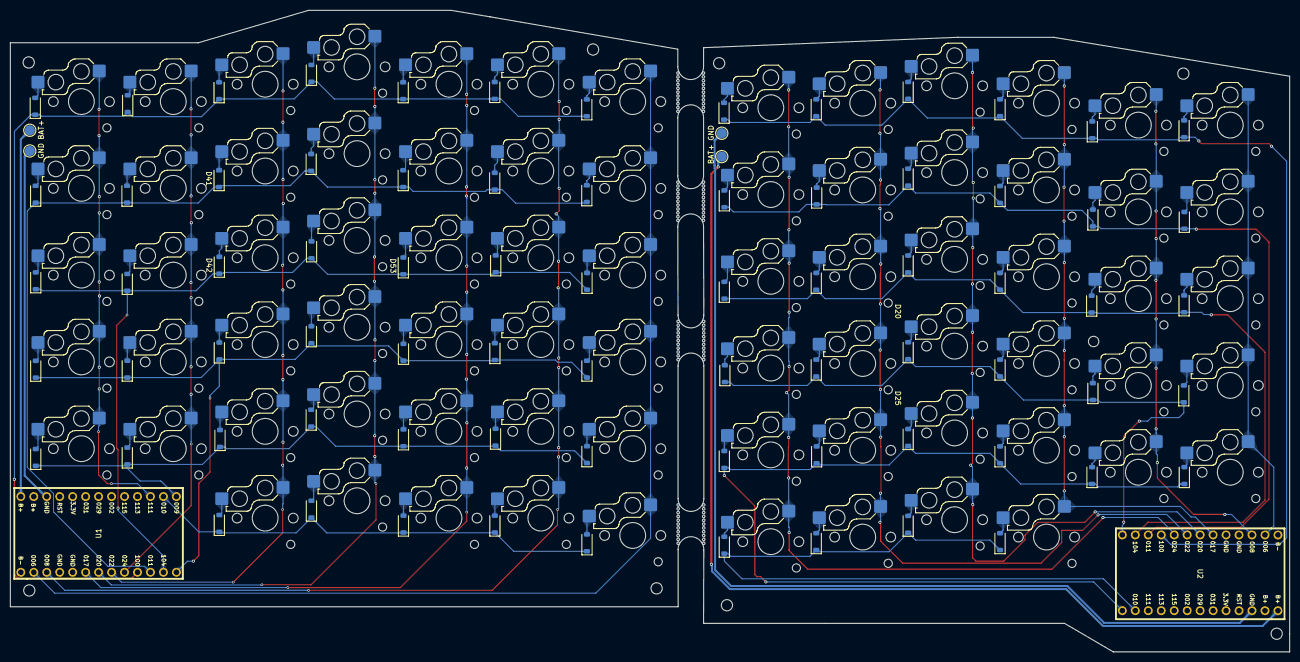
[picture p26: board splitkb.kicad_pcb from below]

Board: 2 copper layers, 250.6 x 125.7 mm, 162 parts (80 on the bottom side), 103 nets.

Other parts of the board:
TP1#2: Bat; TestPoint_Pad_D2.0mm
TP2#2: Gnd; TestPoint_Pad_D2.0mm

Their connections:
GND: TP2#2.1; also elsewhere on the board

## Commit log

2026-03-16 First commit
    Moving all local files to github so they can be used by other people or me on other devices.
    Both left and right half are included.
    [left.kicad_sch, right.kicad_sch, splitkb.kicad_pcb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]
2026-03-18 Made changes to the readme and sorted stuff
    - Added pcb screenshots to the readme and media folder
    - Added the pcb files into a pcb folder for better organization.
    [left.kicad_sch, right.kicad_sch, splitkb.kicad_pcb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]
2026-03-18 Added bill of materials csv file.
2026-03-18 Ran new traces and moved controller
    [splitkb.kicad_pcb, splitkb.step]
2026-03-20 Added a DOM.csv file and deleted the placeholder.
    [BOM nordic split.csv]
2026-03-27 MAde changes to the cad model Made changes to the cad model and added rendered pictures of the left side
    [SplitKBleftv2.f3d, splitkb.kicad_pcb, splitkbleft.step]
2026-03-27 Some more changes to the splitkb cad in kicad
    [splitkbleft.kicad_pcb]
2026-04-10 Added zine page
    [BOM nordic split.csv, BOM.csv]
2026-04-12 Edited PCBs
    - Added mounting holes to both pcbs and schematics
    - Changed the shape and size of both PCBs
    [SketchLeft.dxf, SketchRight.dxf, right.kicad_sch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]
2026-04-12 Changing README - Added information about how to build - Still missing information about software and assembly. - Changed some language at the start of the README.
2026-04-20 Added screws to BOM and changed some stuff in README
    [BOM.csv]
2026-05-07 Edited PCB.
    - Changed the footprint used for the dev board.
    - Ran traces again for the dev board.
    - Made a custom symbol and footprint for the devboard.
    [right.kicad_sch, splitkb.kicad_pcb, splitkb.kicad_sch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]
2026-06-08 Changed readme to have more info.
    [SplitKBleftv2.f3d]
2026-06-10 Changed software.md and readme. Edited kicad to v10
    [right.kicad_sch, splitkb.kicad_sch, untitled.kicad_sch]
2026-06-12 Cleaned up the kicad project.
    [left.kicad_sch, splitkb.kicad_sch, splitkbleft.kicad_pcb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]
2026-06-12 Chnaged the name of the kicad project folder
    [SketchLeft.dxf, SketchRight.dxf, left.kicad_sch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]
2026-06-13 Add 3d files
    - Full project 3d files
    - 3d print 3d files
    [LeftSideOuterShell.3mf, LeftSideOuterShell.step, RightSideOuterShell.3mf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]
2026-06-16 Change kicad folder name
    [SketchLeft.dxf, SketchRight.dxf, left.kicad_sch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]
2026-06-16 Update BOM and kicad files.
    [BOM.csv, splitkb.kicad_pcb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]
2026-06-17 Update BOM
    [BOM.csv]
2026-06-17 Update BOM summary
2026-06-17 Add new 3d files
    [LeftSideOuterShell.3mf, LeftSideOuterShell.step, LeftSideTopPlate.3mf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]
2026-06-18 Add pcb order info
2026-06-19 Fix bom
    [BOM.csv]
2026-06-20 Make total price more obvious.
    [BOM.csv]
2026-06-20 Fix layout of BOM.
    [BOM.csv]
2026-06-20 Bolding fix
    [BOM.csv]
2026-06-20 Update total price.
    [BOM.csv]
2026-06-20 Self printing note
    [BOM.csv]
2026-06-21 Added note on about switches
2026-06-21 Add new render with switches.
2026-06-21 Add new full project files with switches.
2026-06-23 Update prices in BOM.
    [BOM.csv]
2026-06-23 Update prices in BOM
    [BOM.csv]
2026-06-23 Updated 3d models
    [LeftSideOuterShell.3mf, LeftSideOuterShell.step, LeftSideTopPlate.3mf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]
2026-06-23 Update battery position in left side
